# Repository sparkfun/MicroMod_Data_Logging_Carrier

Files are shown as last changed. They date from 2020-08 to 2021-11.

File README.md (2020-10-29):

SparkFun MicroMod Data Logging Carrier Board
========================================

SparkFun MicroMod Data Logging Carrier Board

[SparkFun MicroMod Data Logging Carrier Board (DEV-16829)](https://www.sparkfun.com/products/16829)

The SparkFun MicroMod Data Logging Carrier Board offers a highly customizable, low-power data logging platform using the MicroMod system allowing you to choose your own Processor Board to pair with the Carrier Board. The board features several connections for data collection including I<sup>2</sup>C, SPI and Serial UART.

Repository Contents
-------------------

* **/Examples** - Arduino example sketches
* **/Hardware** - Eagle design files (.brd, .sch)

Documentation
--------------
* **[Hookup Guide](https://learn.sparkfun.com/tutorials/micromod-data-logging-carrier-board-hookup-guide)** - Basic hookup guide for the SparkFun MicroMod Data Logging Carrier Board
* **[MicroMod Info Page](https://ww.sparkfun.com/micromod)** - MicroMod Information Page

Version History
---------------
* **[DEV-16829](https://www.sparkfun.com/products/16829)** - Initial release.

License Information
-------------------

This product is _**open source**_! 

Please review the LICENSE.md file for license information. 

If you have any questions or concerns on licensing, please contact technical support on our [SparkFun forums](https://forum.sparkfun.com/viewforum.php?f=152).

Distributed as-is; no warranty is given.

- Your friends at SparkFun.

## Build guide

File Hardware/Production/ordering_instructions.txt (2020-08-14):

panel size, 144x171mm
PCB thickness, 1.6mm
number of layers, 2
soldermask color, Red
silkscreen color, White
oz copper, 1oz
finish, HASL lead free
stencils, none
pcs per panel, 8
min trace width, 0.1778mm / 0.0070in
min drill size, 0.3048mm / 0.0120in

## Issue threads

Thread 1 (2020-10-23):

Hardware revision request: Voltage divider jumper pad

adamgarbo, 2020-10-23:
Hey folks,

If at some point there is a hardware revision of the MicroMod Data Logger Carrier Board, I would strongly suggest the addition of a jumper pad at the top of the 10kΩ/20kΩ voltage divider that would allow users to cut the voltage supply.

At present, this divider draws a constant 200 uA at 6V and there is no way to disable it, save for cutting the trace, or removing the SMD resistors with a hot air rework station.

Cheers,
Adam

nseidle, 2020-10-23:
A fine idea! Will do.

adamgarbo, 2020-10-28:
Hey @nseidle,

Just received a couple of shiny new Data Logger Carrier Boards today.

I haven't disabled the voltage divider yet, but am measuring a quiescent draw of **~700 uA** with a MicroMod Artemis Processor and 4.2 V lithium battery in deep sleep.

3V3 and VIN jumper pads cut, Qwiic and peripheral AP2112 regulators disabled, LEDs set OUTPUT/LOW and no microSD card is inserted. Assuming ~140 uA for the voltage divider, it appears **>500 uA** is being drawn elsewhere on the board.

Curious who the culprits are!

Cheers,
Adam

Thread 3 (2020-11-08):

Hardware revision request: Improved power efficiency

adamgarbo, 2020-11-08:
Hi there,

I've been super excited to get my hands on the MicroMod Data Logging Carrier Board (MMDLC). I've been putting it through its paces along with an Artemis Processor.

Unfortunately, the quiescent draw of the MMDLC is quite high, so my goal has been to track down the major current draw contributors in order to provide constructive feedback for the next hardware revision (which I realize may take some time). I believe with a few minor changes, the power efficiency of this carrier board could be really improved!

### Methods: Current Measurement
The first step was to characterize the current draw of the MMDLC under a number of different conditions (e.g. disabling LEDs, voltage divider, etc). My methods for measuring the current were as follows:

1. Charge RTC battery for >24 hours via USB-C/LiPo battery
2. Connect a 3.7 V lithium battery (4.2 V nominal), disconnect USB-C connection and allow LiPo charger circuit to settle
3. Place system in deep sleep using the Apollo3 Core RTC library example: `Example6 _LowPower_Alarm`  with added functionality to correctly power down I2C/SPI and G1/G2 pins
4. Disable the onboard voltage divider using a hot-air rework station to remove the top 20kΩ resistor
5. All current measurements were made across MEAS jumper with a Fluke 287 digital multimeter

### Results:

**Table 1.** Quiescent draw of MicroMod Data Logger Carrier Board & Artemis Processor using a 3.7 V (4.2 V) LiPo battery
3V3 LED | VIN LED | PWC | Qwiic | Voltage Divider | Quiescent Draw (mA)
:--: | :--: | :--: | :--: | :--: | :--:
TRUE | TRUE | FALSE | FALSE | TRUE | 2.570
FALSE | TRUE | FALSE | FALSE | TRUE | 0.930
FALSE | FALSE | FALSE | FALSE | TRUE | 0.475
FALSE | FALSE | FALSE | FALSE | FALSE | 0.290

### Discussion:

- Based on the results of Table 1, disabling both LEDs brings the quiescent draw to approximately 500 uA, which is a good start.
- The 20kΩ/10kΩ voltage divider was identified in issue #1 as drawing as much as 200 uA (constant) at 6 V. In this case, disabling the voltage divider by removing the top SMD resistor appeared to save 185 uA. A good savings, but not a modification the average user can will/can do.
- The lowest quiescent draw measured was approximately 290 uA. This is approximately 3-4x greater than the sleep current of other comparable data logging platforms, such as the Adafruit M0 Adalogger (~80 uA) or the SparkFun OpenLog Artemis (~80 uA).
- The question is, what are the sources of this 290 uA? Looking at the schematic and related datasheets, I was able to come up with the following values:

**Table 2.** Max quiescent draw of MMDLCB components
Component | Max Current Draw (uA)
:--: | :--:
AP7361C LDO Regulator | 80
PWC AP2112 LDO Regulator | 80
Qwiic AP2112 LDO Regulator | 80
MCP7381 LiPo Charger | 5?

Based on my experience, the AP2112 LDO regulators will draw around 60 uA. Adding this value for the PWC and Qwiic LDOs with the new AP7361C LDO and MCP7381 charger, I account for approximately 180 uA. This leaves another 100 uA being drawn from components I haven't yet been able to identify.

### Suggestions:
While I'm still trying to identify the other contributors to increased sleep current draw, my hope is to get the conversation started regarding potential modifications that could help to improve the overall power efficiency. A couple of suggestions include:

1. Add (back) P-channel MOSFETs to provide control over PWC/Qwiic regulators. Potential power savings: 160 uA.
    - I noticed in a previous version of the MMDLCB that there were MOSFETs present and in fact, the Hookup Guide still makes reference to them.
2. Voltage divider:
    - (Option 1) Add jumper pad to voltage divider to allow it to be disabled. Potential power savings: 200 uA.
    - (Option 2) Add MOSFET to voltage divider allowing it to be enabled/disabled using a GPIO pin. @PaulZC's Global Artemis Tracker does something similar with the very same voltage divider resistance values:

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

### Summary:
The MicroMod Data Logging Carrier Board has amazing potential and it'd be super if we could get this baby under 100 uA!

Cheers,
Adam

adamgarbo, 2020-11-18:
It just dawned on me that the two AP2112 LDO regulators would only draw a maximum of 1 uA when EN is pulled LOW, which means that there's no real need for P-MOSFETs to disable the power. :man_facepalming:

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

However, this has left me even more confused as to where all the quiescent draw is coming from. Perhaps I should be looking at the Artemis Processor? The investigation continues!

jurvanoerle, 2020-11-24:
Hi there Adam,
I have been trying to do the same power-measurements ( (MMDLC with an Artemis Processor), but I find much higher values.
With all leds disabled, and G0,G1 and G2 disabled (voltage divider in place) I find values >> 1 mA. (and fluctuating). Obviously, I'm doing something wrong.    I have 2 questions:
= could you show your arduino code so I can retry your measurements, and
= where can I find the resistor of the voltage divider I need to cut to reduce power

Regards, Jur

adamgarbo, 2020-11-24:
Hi @jurvanoerle,

Happy to share my code. It's essentially an adapted version of the Apollo3 Example6 _LowPower_Alarm. You can access it here:
https://github.com/adamgarbo/Cryologger_Iceberg_Tracking_Beacon/blob/release-candidate/Software/mmdlcb_artemis_low_power/mmdlcb_artemis_low_power.ino

Please keep in mind that the RTC battery backup onboard the MMDLC takes a *long* time to fully charge. I've found it takes more than 24 hours for the battery to completely charge and for the quiescent draw to achieve its lowest value. Your current draw will be much higher (and flucturate) while it is charging. Also note, as soon as you remove all power sources from the MMDLC, the battery appears to rapidly discharge itself and will require charging again.

I used a hot-air rework station to remove the top SMD resistor from the voltage divider (green arrow). If you prefer to cut the trace (**Warning: permanent change**), you can cut the small trace below the resistor marked by the yellow arrow.

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

Cheers,
Adam

adamgarbo, 2020-11-24:
Oh and before I forget, I believe I may have discovered the source of the high quiescent draw I observed. The CMOS op-amp on the Artemis Processor:

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

As best I can tell, this baby draws 31-50 uA per channel plus 45 uA quiescent draw to power itself. With four of the op-amp channels in use, this could explain the power draw measured with the MMDLCB and Artemis Processor. Hopefully, @nseidle can let us know if this is correct!

Cheers,
Adam

jurvanoerle, 2020-11-26:
Hi Adam,
I managed to brick my board removing the divider/resistor. A new board shows much better results.
The rtc battery discharges quickly indeed after removing all power: the processor and even I2C and leds are powered by the rtc battery, discharging in seconds. For a datalogger board you would expect that the rtc-battery only powers the rtc, lasting for month's: how can I prevent this discharge (cutting a trace somehwere?)
Regards, Jur

adamgarbo, 2020-11-26:
Hi Jur,

Sorry to hear about your board becoming bricked. I'm trying to think about how that could have happened! The voltage divider is in a pretty non-critical area. I've posted an image of the EAGLE board file with what should have been cut or removed in purple. I'm partial to removing the SMD resistor, as it can always be soldered back on.

Regarding the RTC battery backup discharging quickly, I think this will be something that also needs to be addressed in the next hardware revision. I get the sense that the MicroMod ecosystem is still in its infancy, and still has a lot of kinks to be worked out.

Cheers,
Adam

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

jurvanoerle, 2020-12-10:
Hi Adam,
I was succesfull in getting comparable results ( ~0,3 mA in deepsleep), which is perfect for my application, thanks.
BTW, I managed to brick my second carrier board also. On both boards, the serial port is not showing up anymore (not on a PC, nor on a Linux laptop). Is it possible to brick the fdti chip by software (eg by shutting down serial, or shutting down G0/G1/G2 in the arduino code; I have been experimenting a lot with these settings).
I have never experienced this with other arduino boards.
Regards, Jur

adamgarbo, 2021-01-05:
To provide a quick update, I measured the current draw of the MMDLCB with no processor board installed and powered by a 4.2V LiPo.

I made two measurements, as the AP2112 regulators are enabled by default, which required manually pulling their EN pins LOW.

3V3 LED | VIN LED | PWC | Qwiic | Voltage Divider | Quiescent Draw (uA)
-- | -- | -- | -- | -- | --
FALSE | FALSE | TRUE | TRUE | FALSE | 200
FALSE | FALSE | FALSE | FALSE | FALSE | 149

These current draws look to be accounted for by the AP7361C regulator (~80 uA) and the two 100 kΩ pull-up resistors on the AP2112 regulator EN pins (66 uA).

Doing the math, it looks like the Artemis Processor is consuming ~140 uA on its own.

While it'd be nice to see the AP2112s behind FETs, adding a jumper to the voltage divider is by far the easiest solution and would be ideal for all MicroMod carrier boards.

Closed 2021-01-05.

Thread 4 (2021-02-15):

Incorrect battery measurements

adamgarbo, 2021-02-15:
Hi folks,

I noticed that I was getting incorrect battery voltage measurements when powering the MMDLCB with a LiPo battery. After looking at the schematic, this seems to be due to the fact that VBAT has to pass through D3 before getting to the top of the voltage divider. With a multimeter, I measured a battery voltage of 4.2 V but only 4.1 V at the top of the voltage divider, meaning there's a voltage drop of ~0.1 V across D3.

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

This looks to apply to all MicroMod carrier boards with the onboard resistor divider. While it can be addressed using a correction factor in the code, it may be a good idea to add it to the list for the next hardware revision of the MMDLCB.

TL;DR: Feed onboard voltage divider with VBAT and not VIN

Cheers,
Adam

Closed 2024-11-13.

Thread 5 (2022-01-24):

no way to directly power with a 3.3V regulated input?

jerabaul29, 2022-01-24:
I looked at the schematics of this board; is it correct that there is no way to directly power the board with the 3.3V regulated output that typically comes out of a step up step down converter? If this is correct this is very sad, as this drastically limits the usability of the board :( .

Closed 2022-01-24.

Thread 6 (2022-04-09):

incorrect information about power control

paulvha, 2022-04-09:
Looking at the schematics, the hook-up guide, and the examples, the information about the power control is confusing/incorrect.

For both (G1 / Peripheral and G2 / QWIIC) the Enable pin on the LDO is pulled high with a resistor. Hence the power is ALWAYS ON !
_There is NO need for doing a power ON unless GPIO was pulled LOW in the sketch before!_ If people want to preserve power, they should power off the relevant LDO(s)

The hookup guide (https://learn.sparkfun.com/tutorials/micromod-data-logging-carrier-board-hookup-guide) states :

**Take note both Qwiic and 3V3 peripheral power are controlled with a P-Channel MOSFET so the logic is reversed (Power ON = LOW and Power OFF = HIGH).**

### This is 3 times incorrect :
1. There is NO MOSFET, but an LDO
2. Turning  POWER OFF = LOW  (NOT HIGH)
3. Turning POWER ON = HIGH ( which is already due to the pullup resistors.)

regards,
Paul

nseidle, 2022-04-12:
Thanks! Fixed.

Closed 2022-04-12.

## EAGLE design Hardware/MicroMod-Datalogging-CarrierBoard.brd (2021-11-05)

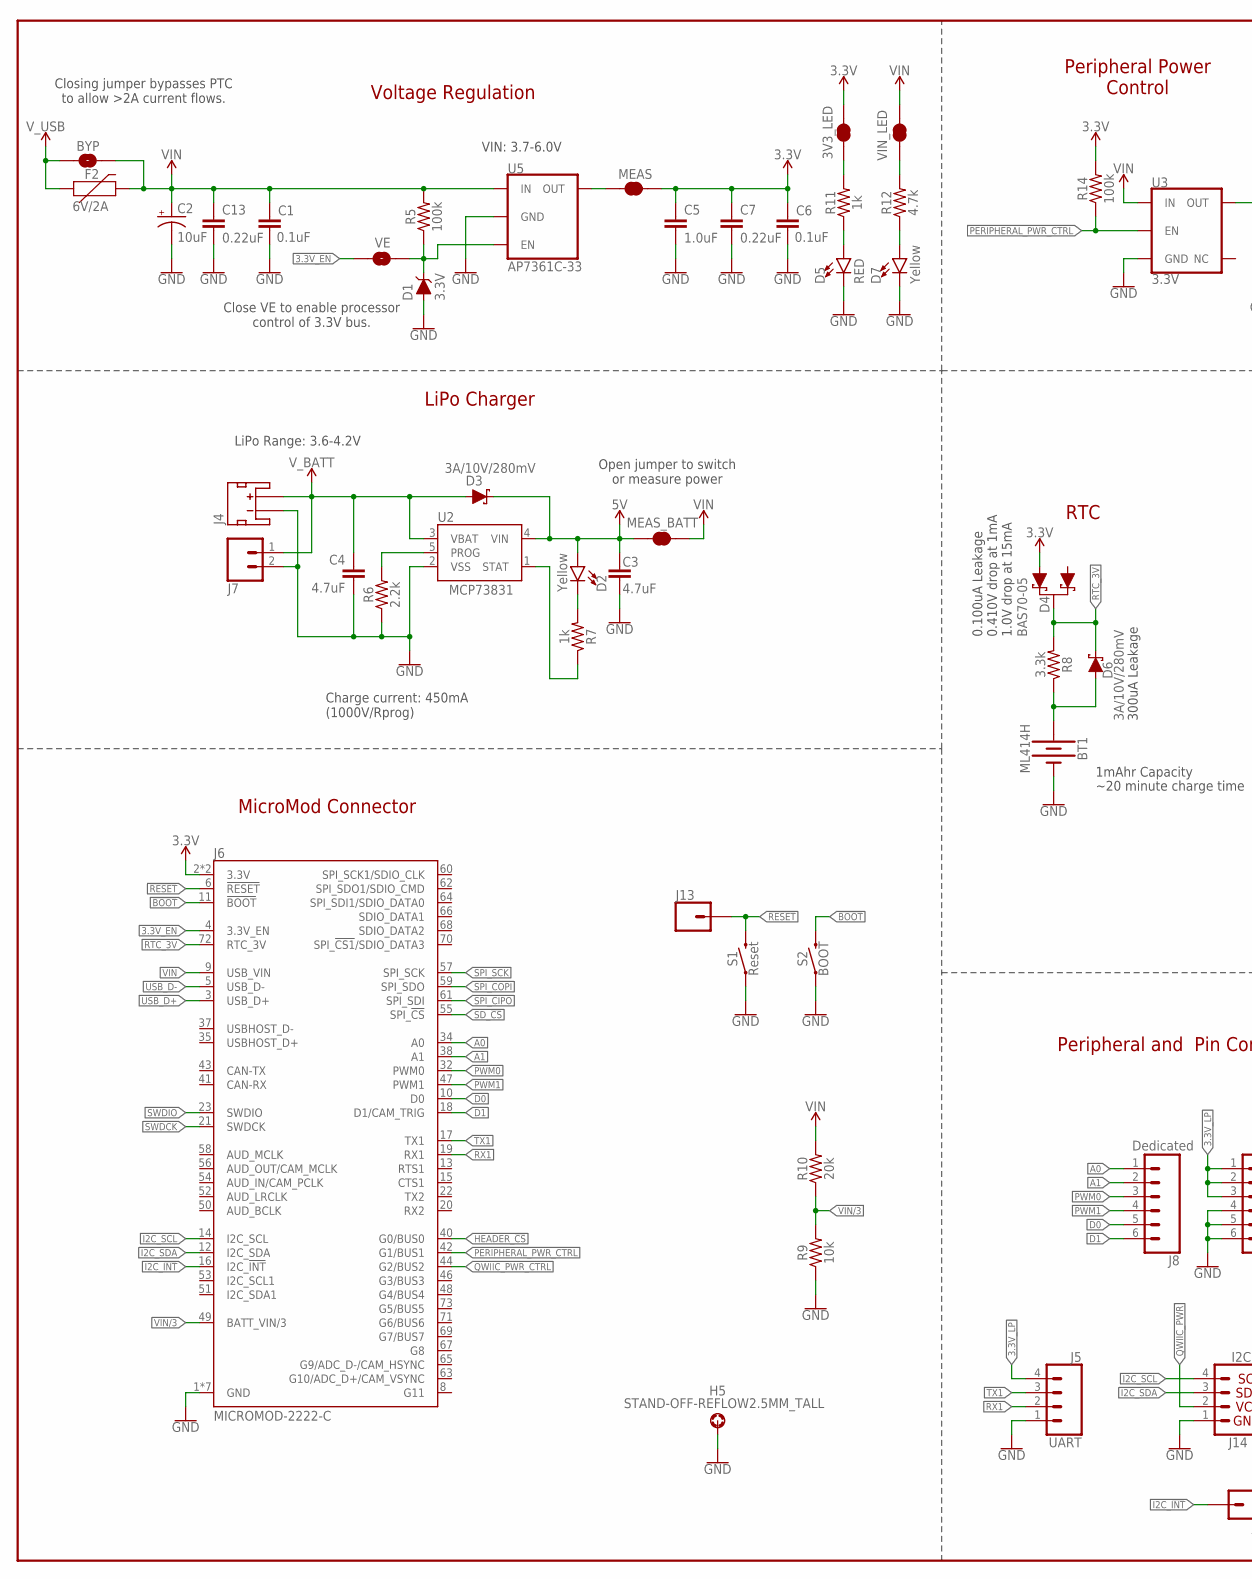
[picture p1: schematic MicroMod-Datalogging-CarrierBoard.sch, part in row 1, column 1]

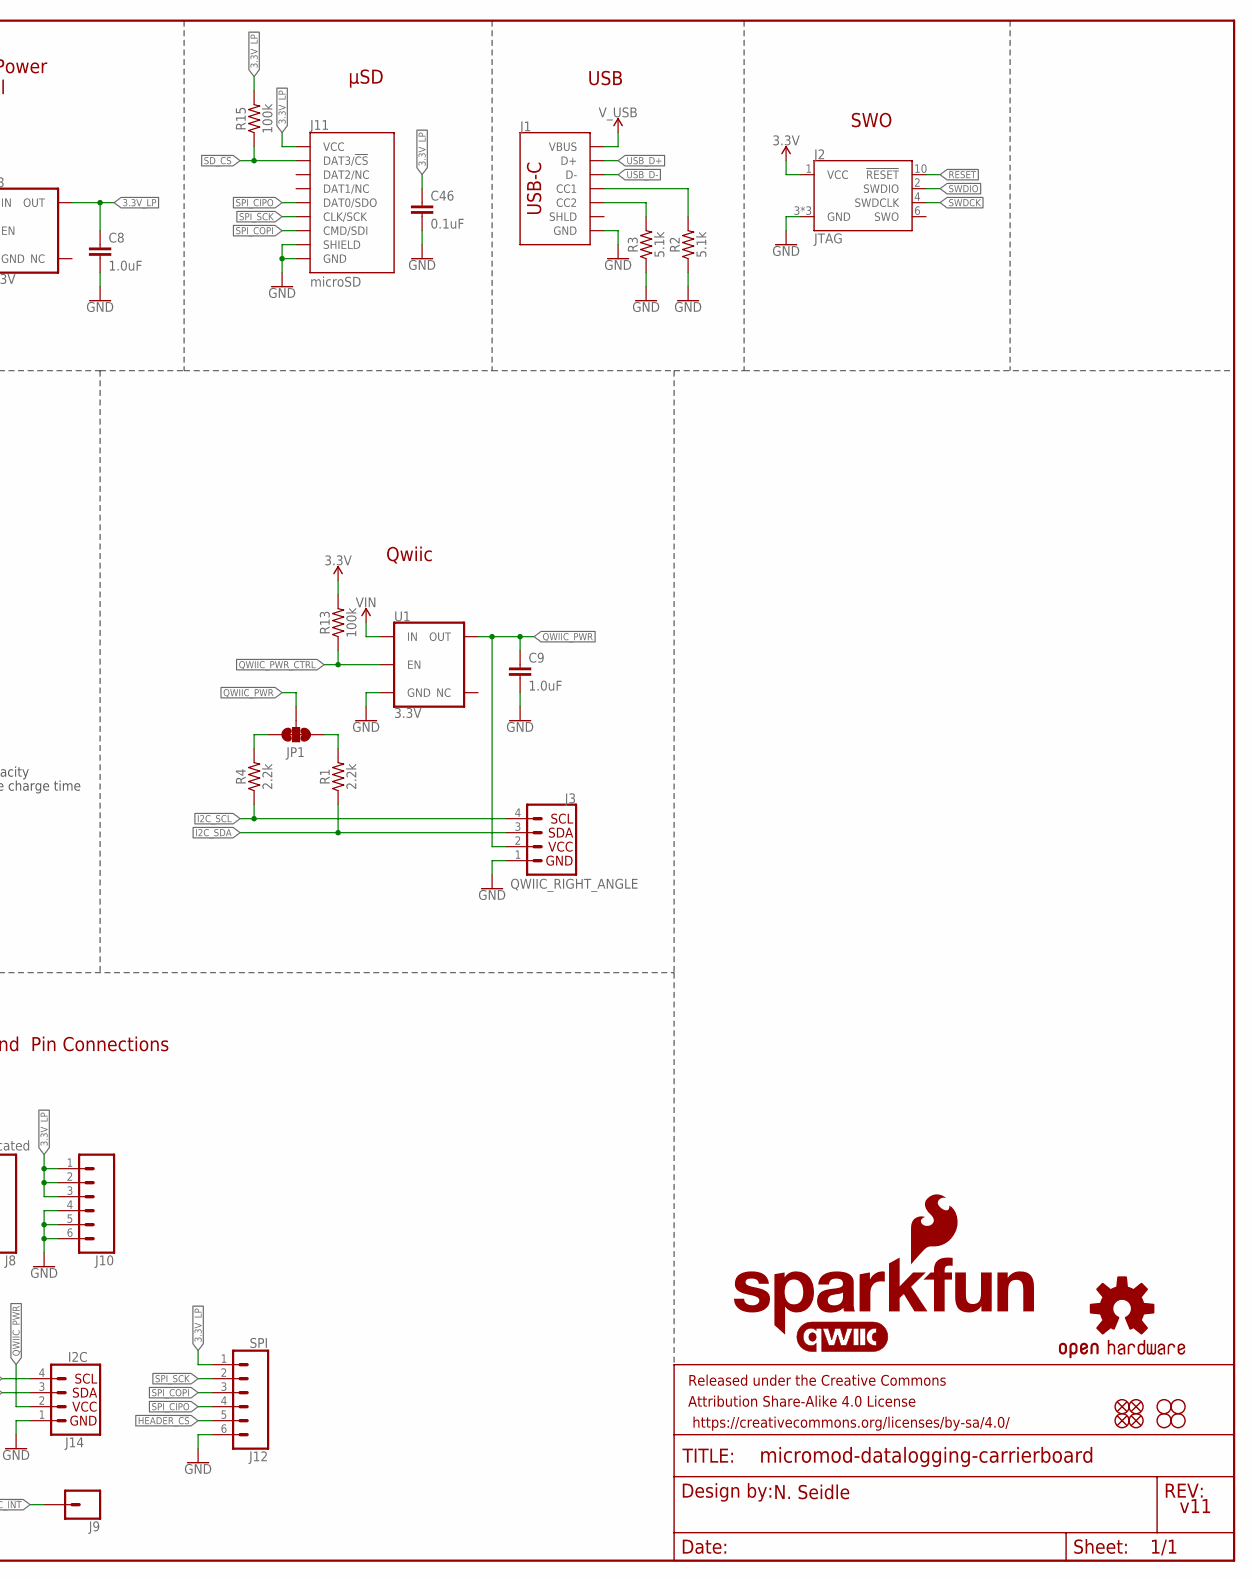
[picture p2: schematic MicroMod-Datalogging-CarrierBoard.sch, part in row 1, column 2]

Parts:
3V3_LED: JUMPER-SMT_2_NC_TRACE_SILK; SMT-JUMPER_2_NC_TRACE_SILK
BT1: ML414H; ML414H_IV01E
BYP: JUMPER-SMT_2_NO_SILK; SMT-JUMPER_2_NO_SILK
C1, C6, C46: 0.1uF; 0603
C2: 10uF; EIA3216
C3, C4: 4.7uF; 0603
C5, C8, C9: 1.0uF; 0603
C7, C13: 0.22uF; 0603
D1: 3.3V; SOD-323
D2, D7: Yellow; LED-0603
D3, D6: 3A/10V/280mV; SOD-323
D4: BAS70-05; SOT23-3
D5: RED; LED-0603
F2: 6V/2A; 1210
FD1, FD2, FD3, FD4: FIDUCIALUFIDUCIAL; FIDUCIAL-MICRO
FRAME1: FRAME-LEDGER; CREATIVE_COMMONS
H1, H2, H3, H4: STAND-OFF
H5: STAND-OFF-REFLOW2.5MM_TALL; STAND-OFF-REFLOW-M2.5
J1: USB_C_2-LAYER_PADS; USB-C-16P-2LAYER-PADS
J2: JTAG; 2X5-PTH-1.27MM
J3: QWIIC_RIGHT_ANGLE; JST04_1MM_RA
J4: JST_2MM_MALE; JST-2-SMD
J5: UART; 1X04_NO_SILK
J6: MICROMOD-2222-C; M.2-CONNECTOR-E
J7: CONN_021X02_NO_SILK; 1X02_NO_SILK
J8: Dedicated; 1X06_NO_SILK
J9, J13: CONN_01PTH_NO_SILK_YES_STOP; 1X01_NO_SILK
J10: CONN_06NO_SILK_NO_POP; 1X06_NO_SILK
J11: microSD; MICRO-SD-SOCKET
J12: SPI; 1X06_NO_SILK
J14: I2C; 1X04_NO_SILK
JP1: JUMPER-SMT_3_2-NC_TRACE_SILK; SMT-JUMPER_3_2-NC_TRACE_SILK
LOGO1: SFE_LOGO_NAME_FLAME.1_INCH; SFE_LOGO_NAME_FLAME_.1
LOGO2: QWIIC_LOGO_CONNECTOR; QWIIC_5.5MM
LOGO3: OSHW-LOGOMINI; OSHW-LOGO-MINI
MEAS: JUMPER-COMBO_2_NC_TRACE; COMBO-JUMPER_2_NC_TRACE
MEAS_BATT: JUMPER-COMBO_2_NC_TRACE; COMBO-JUMPER_2_NC_TRACE
R1, R4, R6: 2.2k; 0603
R2, R3: 5.1k; 0603
R5, R13, R14, R15: 100k; 0603
R7, R11: 1k; 0603
R8: 3.3k; 0603
R9: 10k; 0603
R10: 20k; 0603
R12: 4.7k; 0603
S1: Reset; TACTILE_SWITCH_SMD_5.2MM
S2: BOOT; TACTILE_SWITCH_SMD_5.2MM
U1, U3: 3.3V; SOT23-5
U2: MCP73831; SOT23-5
U5: AP7361C-33; UDFN-8
VE: JUMPER-SMT_2_NO_SILK; SMT-JUMPER_2_NO_SILK
VIN_LED: JUMPER-SMT_2_NC_TRACE_SILK; SMT-JUMPER_2_NC_TRACE_SILK

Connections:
3.3V: 3V3_LED.2, C5.1, C6.1, C7.1, D4.2 (A1), J2.1 (VCC), J6.2 (3.3V), J6.74 (3.3V), MEAS.2, MEAS.4 (2), R13.2, R14.2
3.3V_EN: J6.4 (3.3V_EN), VE.1
3.3V_EN_VE: D1.C, R5.1, U5.5 (EN), VE.2
3.3V_LP: C8.1, C46.1, J5.4, J10.1, J10.2, J10.3, J11.VCC, J12.1, R15.2, U3.5 (OUT)
5V: C3.1, D2.A, D3.C, MEAS_BATT.1, MEAS_BATT.3 (1), U2.4 (VIN)
!BOOT!: J6.11 (!BOOT!), S2.3 (2), S2.4 (2)
!RESET!: J2.10 (!RESET), J6.6 (!RESET!), J13.1, S1.3 (2), S1.4 (2)
A0: J6.34 (A0), J8.1
A1: J6.38 (A1), J8.2
CHG_LED: R7.1, U2.1 (STAT)
D0: J6.10 (D0), J8.5
D1: J6.18 (D1/CAM_TRIG), J8.6
GND: BT1.-, C1.2, C2.-, C3.2, C4.2, C5.2, C6.2, C7.2, C8.2, C9.2, C13.2, C46.2, D1.A, D5.C, D7.C, H5.1, J1.GND, J1.GND2 (GND), J2.3 (GND), J2.5 (GND), J2.9 (GND), J3.1, J4.1 (-), J5.1, J6.1 (GND), J6.7 (GND), J6.33 (GND), J6.36 (GND), J6.39 (GND), J6.45 (GND), J6.75 (GND), J7.2, J10.4, J10.5, J10.6, J11.CD1 (SHIELD), J11.GND, J11.GND1 (GND), J11.GND3 (GND), J12.6, J14.1, R2.1, R3.1, R6.1, R9.1, S1.1, S1.2 (1), S2.1, S2.2 (1), U1.2 (GND), U2.2 (VSS), U3.2 (GND), U5.4 (GND), U5.EP (GND)
HEADER_!CS!: J6.40 (G0/BUS0), J12.5
I2C_!INT!: J6.16 (I2C_!INT!), J9.1
I2C_SCL: J3.4, J6.14 (I2C_SCL), J14.4, R4.1
I2C_SDA: J3.3, J6.12 (I2C_SDA), J14.3, R1.1
unnamed: MEAS.1, MEAS.3 (1), U5.1 (OUT)
unnamed: JP1.3, R4.2
unnamed: JP1.1, R1.2
unnamed: D2.C, R7.2
unnamed: D5.A, R11.1
unnamed: 3V3_LED.1, R11.2
unnamed: R6.2, U2.5 (PROG)
unnamed: R12.2, VIN_LED.1
unnamed: D7.A, R12.1
unnamed: J1.A5 (CC1), R2.2
unnamed: J1.B5 (CC2), R3.2
unnamed: BT1.+, D6.A, R8.1
PERIPHERAL_PWR_CTRL: J6.42 (G1/BUS1), R14.1, U3.3 (EN)
PWM0: J6.32 (PWM0), J8.3
PWM1: J6.47 (PWM1), J8.4
QWIIC_PWR: C9.1, J3.2, J14.2, JP1.2, U1.5 (OUT)
QWIIC_PWR_CTRL: J6.44 (G2/BUS2), R13.1, U1.3 (EN)
RTC_3V: D4.3 (C), D6.C, J6.72 (RTC_3V), R8.2
RX1: J5.2, J6.19 (RX1)
SD_!CS!: J6.55 (SPI_!CS!), J11.CS/DAT3 (DAT3/!CS!), R15.1
SPI_CIPO: J6.61 (SPI_SDI), J11.DO/DAT0 (DAT0/SDO), J12.4
SPI_COPI: J6.59 (SPI_SDO), J11.DI/CMD (CMD/SDI), J12.3
SPI_SCK: J6.57 (SPI_SCK), J11.SCLK (CLK/SCK), J12.2
SWDCK: J2.4 (SWDCLK), J6.21 (SWDCK)
SWDIO: J2.2 (SWDIO), J6.23 (SWDIO)
TX1: J5.3, J6.17 (TX1)
USB_D+: J1.A6 (D+), J1.B6 (D+), J6.3 (USB_D+)
USB_D-: J1.A7 (D-), J1.B7 (D-), J6.5 (USB_D-)
VIN: BYP.2, C1.1, C2.+, C13.1, F2.2, J6.9 (USB_VIN), MEAS_BATT.2, MEAS_BATT.4 (2), R5.2, R10.2, U1.1 (IN), U3.1 (IN), U5.8 (IN), VIN_LED.2
VIN/3: J6.49 (BATT_VIN/3), R9.2, R10.1
V_BATT: C4.1, D3.A, J4.2 (+), J7.1, U2.3 (VBAT)
V_USB: BYP.1, F2.1, J1.VBUS1 (VBUS), J1.VBUS2 (VBUS)

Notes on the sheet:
μSD
300uA Leakage
~20 minute charge time
1mAhr Capacity
SWO
USB
Peripheral and Pin Connections
Qwiic
RTC
Voltage Regulation
MicroMod Connector
LiPo Charger
LiPo Range: 3.6-4.2V
Charge current: 450mA (1000V/Rprog)
Open jumper to switch or measure power
Peripheral Power Control
0.100uA Leakage 0.410V drop at 1mA 1.0V drop at 15mA
Closing jumper bypasses PTC to allow >2A current flows.
VIN: 3.7-6.0V
N. Seidle
v11
Close VE to enable processor control of 3.3V bus.

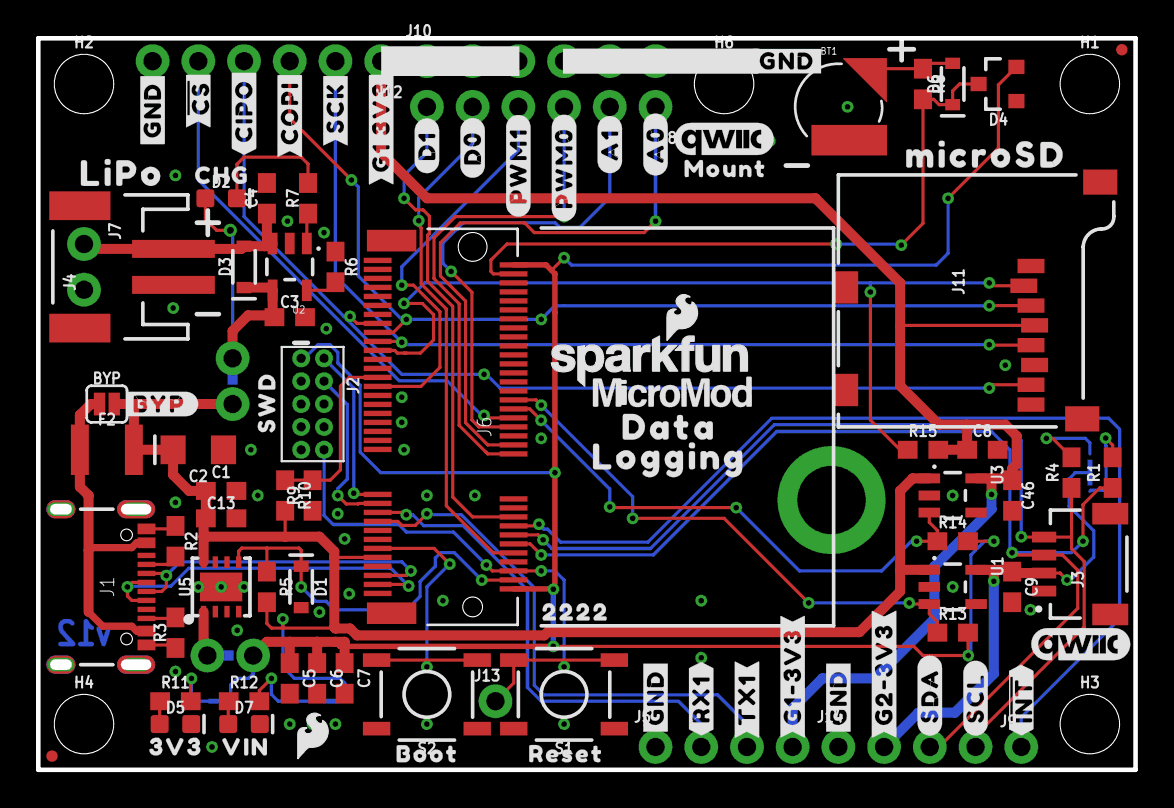
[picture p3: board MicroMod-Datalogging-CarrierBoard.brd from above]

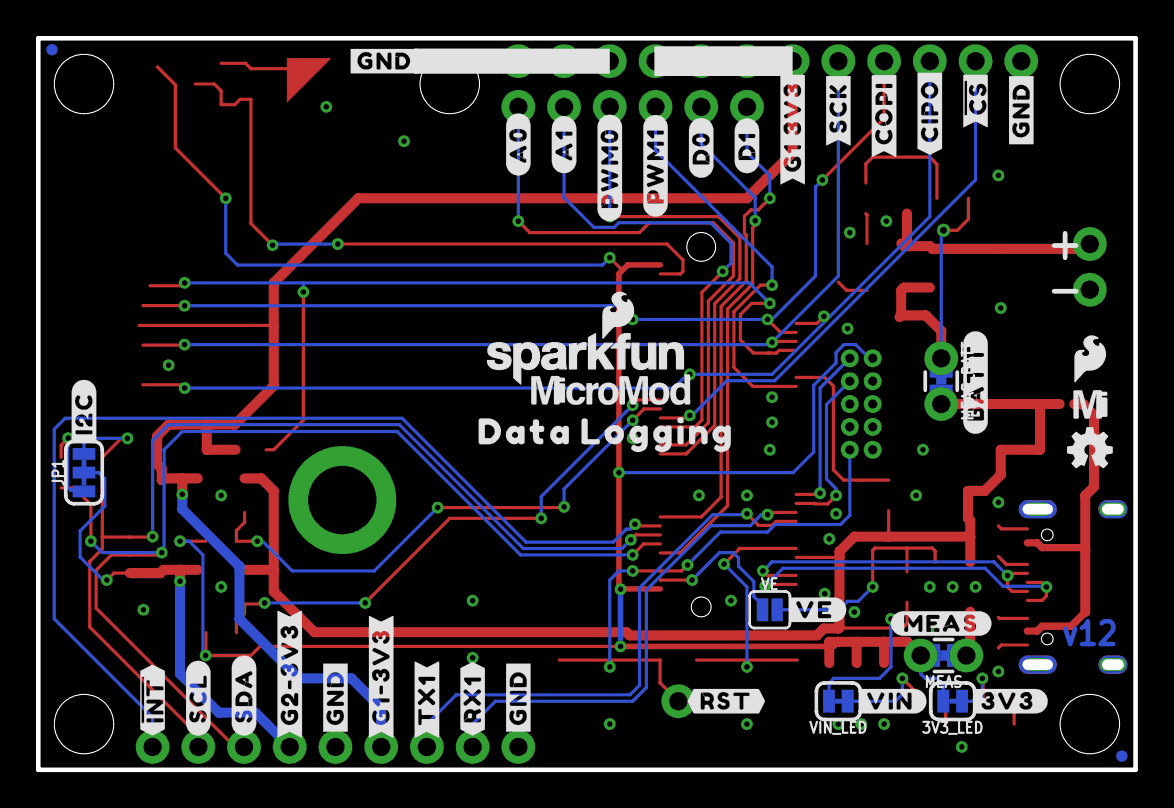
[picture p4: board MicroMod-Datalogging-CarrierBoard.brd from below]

Board: 2 copper layers, 61.0 x 40.6 mm, 149 parts (44 on the bottom side), 49 nets.

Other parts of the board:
H6: STAND-OFF
LOGO4: SFE_LOGO_NAME_FLAME.1_INCH; SFE_LOGO_NAME_FLAME_.1
LOGO5: QWIIC_LOGO_CONNECTOR; QWIIC_5.5MM
U$1, U$66: SFE_LOGO_FLAME_.1
U$2, U$76: #D1#0
U$3, U$77: #D0#0
U$4: #3V3#2
U$5: #BATT#0
U$6, U$18, U$24, U$27, U$32, U$34, U$36, U$42: #GND#0
U$7, U$8: #SCK#0
U$9, U$81: #PWM1#1
U$10, U$80: #PWM0#0
U$11: MICROSD0
U$12, U$79: #A1#2
U$13, U$78: #A0#3
U$14: MOUNT0
U$15: LIPO0
U$16, U$23: DATA0
U$17, U$86: #RX1#1
U$19, U$26: LOGGING1
U$20: 22220
U$21, U$89: #TX1#2
U$22: #I2C#0
U$25, U$90: #G1#3V3#0
U$28: #MEAS#3
U$29, U$83: #G2#3V3#3
U$30: #RST#0
U$31, U$88: #SDA#4
U$33: #VIN#1
U$35, U$87: #SCL#5
U$37, U$63: MICROMOD_LOGO_.35
U$38, U$82: ##INT##6
U$39, U$40: #CIPO#0
U$41: #VE#0
U$50, U$51: ##CS##0
U$62: MICROMOD_MI_LOGO_.35
U$64, U$65: #G1_3V3#0
U$72, U$73: #COPI#0
U$91: BOOT0
U$92: RESET1
U$93: 3V30
U$94: VIN1
U$95: #BYP#3
U$96: CHG1
U$97: SWD0

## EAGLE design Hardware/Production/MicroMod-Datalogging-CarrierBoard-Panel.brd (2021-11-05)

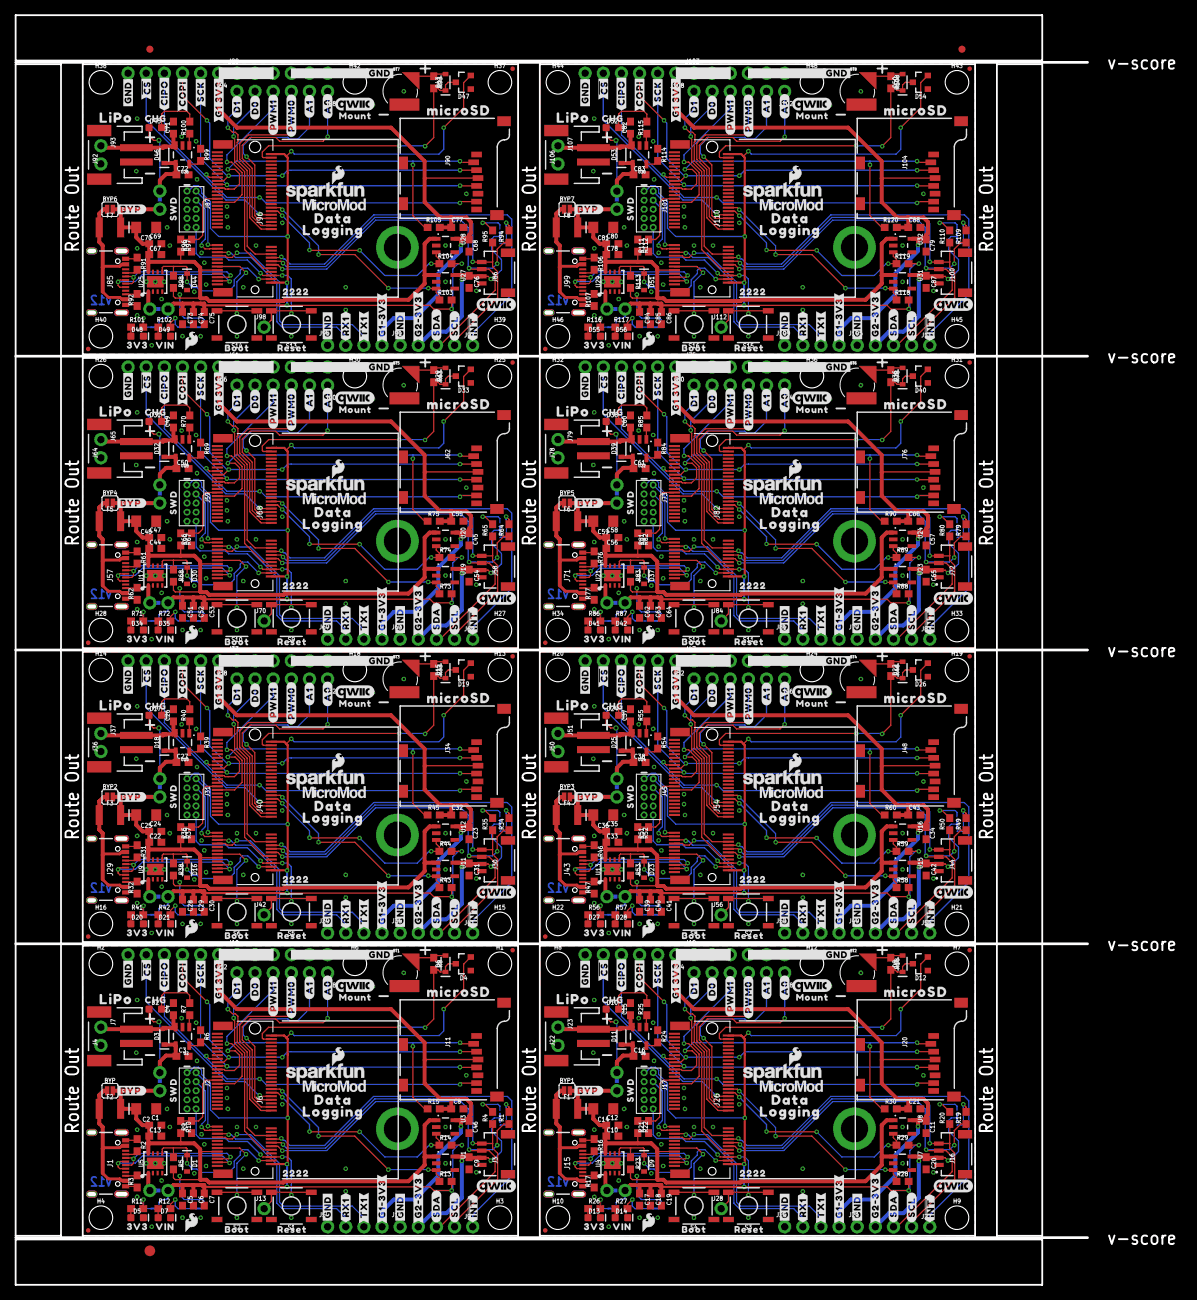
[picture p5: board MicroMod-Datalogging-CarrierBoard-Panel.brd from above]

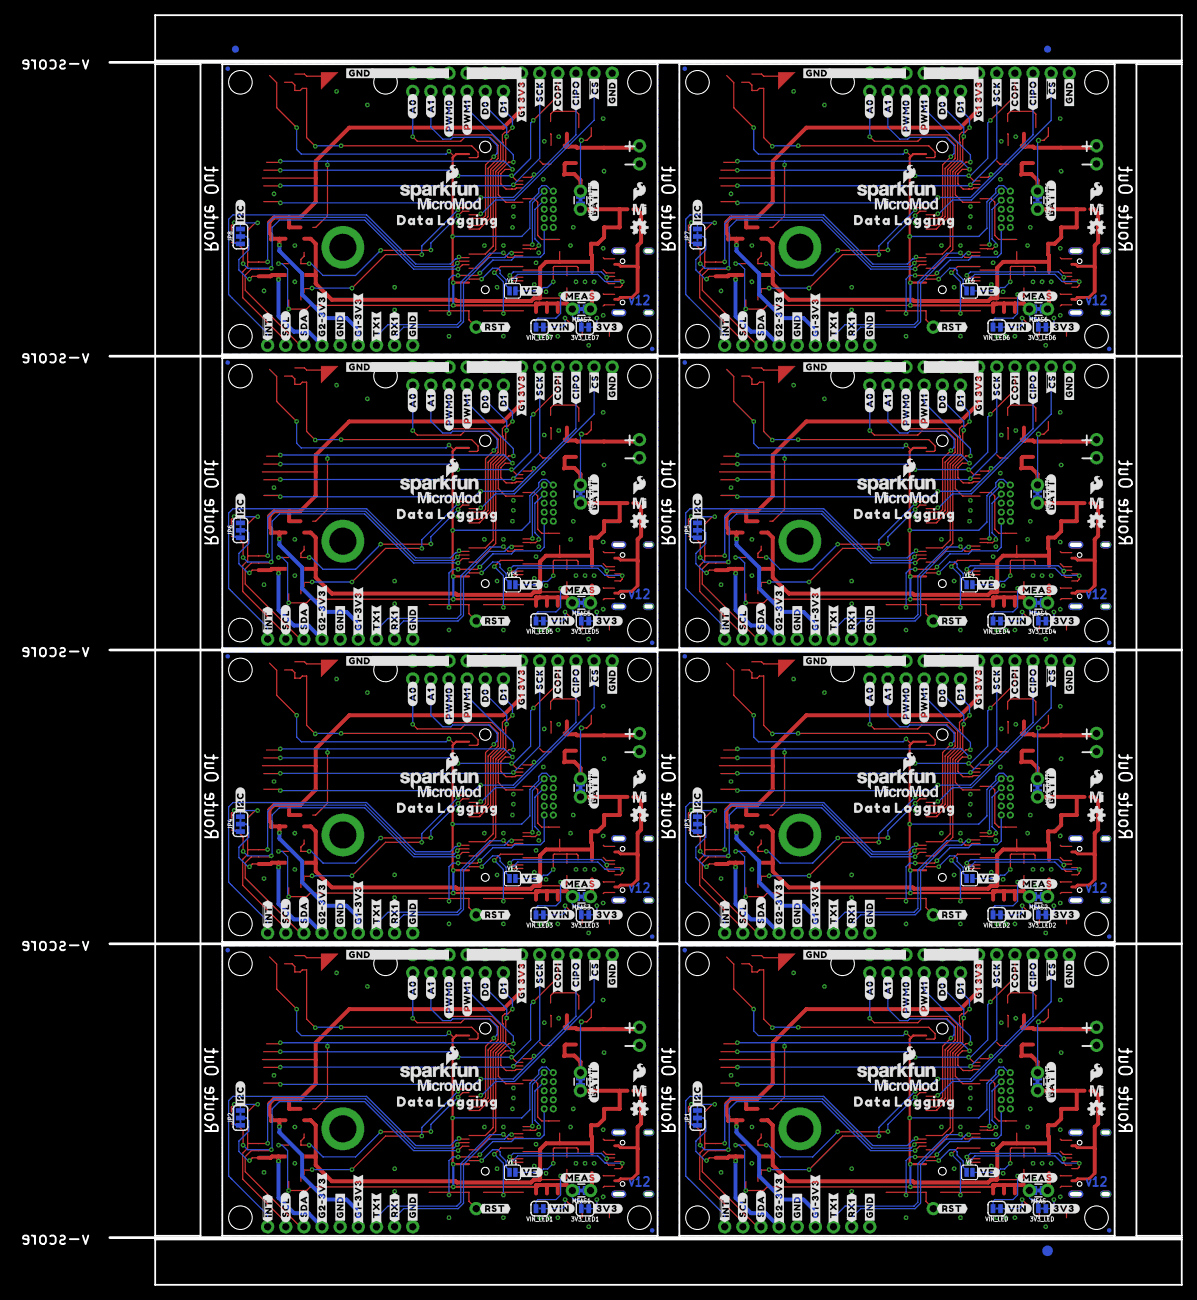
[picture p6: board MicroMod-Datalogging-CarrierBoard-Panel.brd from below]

Board: 2 copper layers, 150.1 x 177.8 mm, 1190 parts (355 on the bottom side), 392 nets.

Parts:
3V3_LED, 3V3_LED1, 3V3_LED2, 3V3_LED3, 3V3_LED4, 3V3_LED5, 3V3_LED6, 3V3_LED7: SMT-JUMPER_2_NC_TRACE_SILK
BT1, BT2, BT3, BT4, BT5, BT6, BT7, BT8: ML414H; ML414H_IV01E
BYP, BYP1, BYP2, BYP3, BYP4, BYP5, BYP6, BYP7: JUMPER-SMT_2_NO_SILK; SMT-JUMPER_2_NO_SILK
C1, C6, C11, C12, C18, C23, C24, C29, C34, C35, C40, C45, C46, C47, C52, C57, C58, C63, C68, C69, C74, C79, C80, C85: 0.1uF; 0603
C2, C14, C25, C36, C48, C59, C70, C81: 10uF; EIA3216
C3, C4, C15, C16, C26, C27, C37, C38, C49, C50, C60, C61, C71, C72, C82, C83: 4.7uF; 0603
C5, C8, C9, C17, C20, C21, C28, C31, C32, C39, C42, C43, C51, C54, C55, C62, C65, C66, C73, C76, C77, C84, C87, C88: 1.0uF; 0603
C7, C10, C13, C19, C22, C30, C33, C41, C44, C53, C56, C64, C67, C75, C78, C86: 0.22uF; 0603
D1, D9, D16, D23, D30, D37, D44, D51: 3.3V; SOD-323
D2, D7, D10, D14, D17, D21, D24, D28, D31, D35, D38, D42, D45, D49, D52, D56: Yellow; LED-0603
D3, D6, D8, D11, D15, D18, D22, D25, D29, D32, D36, D39, D43, D46, D50, D53: 3A/10V/280mV; SOD-323
D4, D12, D19, D26, D33, D40, D47, D54: BAS70-05; SOT23-3
D5, D13, D20, D27, D34, D41, D48, D55: RED; LED-0603
E$1, E$2, E$3, E$4: FIDUCIAL-1X2
E$5, E$6: FIDUCIAL-1.5X3
F1, F2, F3, F4, F5, F6, F7, F8: 6V/2A; 1210
FD1, FD2, FD3, FD4, FD5, FD6, FD7, FD8, FD9, FD10, FD11, FD12, FD13, FD14, FD15, FD16, FD17, FD18, FD19, FD20, FD21, FD22, FD23, FD24, FD25, FD26, FD27, FD28, FD29, FD30, FD31, FD32: FIDUCIALUFIDUCIAL; FIDUCIAL-MICRO
H1, H2, H3, H4, H6, H7, H8, H9, H10, H12, H13, H14, H15, H16, H18, H19, H20, H21, H22, H24, H25, H26, H27, H28, H30, H31, H32, H33, H34, H36, H37, H38, H39, H40, H42, H43, H44, H45, H46, H48: STAND-OFF
H5, H11, H17, H23, H29, H35, H41, H47: STAND-OFF-REFLOW2.5MM_TALL; STAND-OFF-REFLOW-M2.5
J1, J15, J29, J43, J57, J71, J85, J99: USB-C-16P-2LAYER-PADS
J2, J17, J31, J45, J59, J73, J87, J101: JTAG; 2X5-PTH-1.27MM
J3, J16, J30, J44, J58, J72, J86, J100: QWIIC_RIGHT_ANGLE; JST04_1MM_RA
J4, J22, J36, J50, J64, J78, J92, J106: JST-2-SMD
J5, J25, J39, J53, J67, J81, J95, J109: UART; 1X04_NO_SILK
J6, J26, J40, J54, J68, J82, J96, J110: MICROMOD-2222-C; M.2-CONNECTOR-E
J7, J23, J37, J51, J65, J79, J93, J107: 1X02_NO_SILK
J8, J18, J32, J46, J60, J74, J88, J102: Dedicated; 1X06_NO_SILK
J9, J13, J27, J28, J41, J42, J55, J56, J69, J70, J83, J84, J97, J98, J111, J112: 1X01_NO_SILK
J10, J19, J33, J47, J61, J75, J89, J103: 1X06_NO_SILK
J11, J20, J34, J48, J62, J76, J90, J104: microSD; MICRO-SD-SOCKET
J12, J24, J38, J52, J66, J80, J94, J108: SPI; 1X06_NO_SILK
J14, J21, J35, J49, J63, J77, J91, J105: I2C; 1X04_NO_SILK
JP1, JP2, JP3, JP4, JP5, JP6, JP7, JP8: SMT-JUMPER_3_2-NC_TRACE_SILK
LOGO1, LOGO4, LOGO6, LOGO9, LOGO11, LOGO14, LOGO16, LOGO19, LOGO21, LOGO24, LOGO26, LOGO29, LOGO31, LOGO34, LOGO36, LOGO39: SFE_LOGO_NAME_FLAME.1_INCH; SFE_LOGO_NAME_FLAME_.1
LOGO2, LOGO5, LOGO7, LOGO10, LOGO12, LOGO15, LOGO17, LOGO20, LOGO22, LOGO25, LOGO27, LOGO30, LOGO32, LOGO35, LOGO37, LOGO40: QWIIC_LOGO_CONNECTOR; QWIIC_5.5MM
LOGO3, LOGO8, LOGO13, LOGO18, LOGO23, LOGO28, LOGO33, LOGO38: OSHW-LOGOMINI; OSHW-LOGO-MINI
MEAS, MEAS1, MEAS2, MEAS3, MEAS4, MEAS5, MEAS6, MEAS7: COMBO-JUMPER_2_NC_TRACE
MEAS_BATT, MEAS_BATT1, MEAS_BATT2, MEAS_BATT3, MEAS_BATT4, MEAS_BATT5, MEAS_BATT6, MEAS_BATT7: COMBO-JUMPER_2_NC_TRACE
R1, R4, R6, R19, R20, R24, R34, R35, R39, R49, R50, R54, R64, R65, R69, R79, R80, R84, R94, R95, R99, R109, R110, R114: 2.2k; 0603
R2, R3, R16, R17, R31, R32, R46, R47, R61, R62, R76, R77, R91, R92, R106, R107: 5.1k; 0603
R5, R13, R14, R15, R23, R28, R29, R30, R38, R43, R44, R45, R53, R58, R59, R60, R68, R73, R74, R75, R83, R88, R89, R90, R98, R103, R104, R105, R113, R118, R119, R120: 100k; 0603
R7, R11, R25, R26, R40, R41, R55, R56, R70, R71, R85, R86, R100, R101, R115, R116: 1k; 0603
R8, R18, R33, R48, R63, R78, R93, R108: 3.3k; 0603
R9, R21, R36, R51, R66, R81, R96, R111: 10k; 0603
R10, R22, R37, R52, R67, R82, R97, R112: 20k; 0603
R12, R27, R42, R57, R72, R87, R102, R117: 4.7k; 0603
S1, S3, S5, S7, S9, S11, S13, S15: Reset; TACTILE_SWITCH_SMD_5.2MM
S2, S4, S6, S8, S10, S12, S14, S16: BOOT; TACTILE_SWITCH_SMD_5.2MM
U1, U3, U7, U8, U11, U12, U15, U16, U19, U20, U23, U24, U27, U28, U31, U32: 3.3V; SOT23-5
U2, U6, U10, U14, U18, U22, U26, U30: MCP73831; SOT23-5
U4, U5, U9, U13, U17, U21, U25, U29: AP7361C-33; UDFN-8
U$1, U$45, U$47, U$66, U$145, U$147, U$216, U$218, U$287, U$289, U$358, U$360, U$429, U$431, U$500, U$502: SFE_LOGO_FLAME_.1
U$2, U$58, U$76, U$118, U$156, U$189, U$227, U$260, U$298, U$331, U$369, U$402, U$440, U$473, U$511, U$544: #D1#0
U$3, U$59, U$77, U$119, U$157, U$190, U$228, U$261, U$299, U$332, U$370, U$403, U$441, U$474, U$512, U$545: #D0#0
U$4, U$133, U$204, U$275, U$346, U$417, U$488, U$559: #3V3#2
U$5, U$137, U$208, U$279, U$350, U$421, U$492, U$563: #BATT#0
U$6, U$18, U$24, U$27, U$32, U$34, U$36, U$42, U$105, U$106, U$107, U$108, U$109, U$110, U$138, U$142, U$176, U$177, U$178, U$179, U$180, U$181, U$209, U$213, U$247, U$248, U$249, U$250, U$251, U$252, U$280, U$284, U$318, U$319, U$320, U$321, U$322, U$323, U$351, U$355, U$389, U$390, U$391, U$392, U$393, U$394, U$422, U$426, U$460, U$461, U$462, U$463, U$464, U$465, U$493, U$497, U$531, U$532, U$533, U$534, U$535, U$536, U$564, U$568: #GND#0
U$7, U$8, U$52, U$53, U$150, U$151, U$221, U$222, U$292, U$293, U$363, U$364, U$434, U$435, U$505, U$506: #SCK#0
U$9, U$68, U$81, U$120, U$161, U$191, U$232, U$262, U$303, U$333, U$374, U$404, U$445, U$475, U$516, U$546: #PWM1#1
U$10, U$67, U$80, U$121, U$160, U$192, U$231, U$263, U$302, U$334, U$373, U$405, U$444, U$476, U$515, U$547: #PWM0#0
U$11, U$125, U$196, U$267, U$338, U$409, U$480, U$551: MICROSD0
U$12, U$61, U$79, U$122, U$159, U$193, U$230, U$264, U$301, U$335, U$372, U$406, U$443, U$477, U$514, U$548: #A1#2
U$13, U$60, U$78, U$123, U$158, U$194, U$229, U$265, U$300, U$336, U$371, U$407, U$442, U$478, U$513, U$549: #A0#3
U$14, U$124, U$195, U$266, U$337, U$408, U$479, U$550: MOUNT0
U$15, U$126, U$197, U$268, U$339, U$410, U$481, U$552: LIPO0
U$16, U$23, U$127, U$130, U$198, U$201, U$269, U$272, U$340, U$343, U$411, U$414, U$482, U$485, U$553, U$556: DATA0
U$17, U$71, U$86, U$111, U$164, U$182, U$235, U$253, U$306, U$324, U$377, U$395, U$448, U$466, U$519, U$537: #RX1#1
U$19, U$26, U$128, U$131, U$199, U$202, U$270, U$273, U$341, U$344, U$412, U$415, U$483, U$486, U$554, U$557: LOGGING1
U$20, U$129, U$200, U$271, U$342, U$413, U$484, U$555: 22220
U$21, U$84, U$89, U$112, U$167, U$183, U$238, U$254, U$309, U$325, U$380, U$396, U$451, U$467, U$522, U$538: #TX1#2
U$22, U$132, U$203, U$274, U$345, U$416, U$487, U$558: #I2C#0
U$25, U$85, U$90, U$113, U$168, U$184, U$239, U$255, U$310, U$326, U$381, U$397, U$452, U$468, U$523, U$539: #G1#3V3#0
U$28, U$134, U$205, U$276, U$347, U$418, U$489, U$560: #MEAS#3
U$29, U$70, U$83, U$114, U$163, U$185, U$234, U$256, U$305, U$327, U$376, U$398, U$447, U$469, U$518, U$540: #G2#3V3#3
U$30, U$135, U$206, U$277, U$348, U$419, U$490, U$561: #RST#0
U$31, U$75, U$88, U$115, U$166, U$186, U$237, U$257, U$308, U$328, U$379, U$399, U$450, U$470, U$521, U$541: #SDA#4
U$33, U$136, U$207, U$278, U$349, U$420, U$491, U$562: #VIN#1
U$35, U$74, U$87, U$116, U$165, U$187, U$236, U$258, U$307, U$329, U$378, U$400, U$449, U$471, U$520, U$542: #SCL#5
U$37, U$44, U$46, U$63, U$144, U$146, U$215, U$217, U$286, U$288, U$357, U$359, U$428, U$430, U$499, U$501: MICROMOD_LOGO_.35
U$38, U$69, U$82, U$117, U$162, U$188, U$233, U$259, U$304, U$330, U$375, U$401, U$446, U$472, U$517, U$543: ##INT##6
U$39, U$40, U$139, U$140, U$210, U$211, U$281, U$282, U$352, U$353, U$423, U$424, U$494, U$495, U$565, U$566: #CIPO#0
U$41, U$141, U$212, U$283, U$354, U$425, U$496, U$567: #VE#0
U$43, U$62, U$143, U$214, U$285, U$356, U$427, U$498: MICROMOD_MI_LOGO_.35
U$48, U$49, U$72, U$73, U$148, U$149, U$219, U$220, U$290, U$291, U$361, U$362, U$432, U$433, U$503, U$504: #COPI#0
U$50, U$51, U$54, U$55, U$152, U$153, U$223, U$224, U$294, U$295, U$365, U$366, U$436, U$437, U$507, U$508: ##CS##0
U$56, U$57, U$64, U$65, U$154, U$155, U$225, U$226, U$296, U$297, U$367, U$368, U$438, U$439, U$509, U$510: #G1_3V3#0
U$91, U$98, U$169, U$240, U$311, U$382, U$453, U$524: BOOT0
U$92, U$99, U$170, U$241, U$312, U$383, U$454, U$525: RESET1
U$93, U$100, U$171, U$242, U$313, U$384, U$455, U$526: 3V30
U$94, U$101, U$172, U$243, U$314, U$385, U$456, U$527: VIN1
U$95, U$102, U$173, U$244, U$315, U$386, U$457, U$528: #BYP#3
U$96, U$103, U$174, U$245, U$316, U$387, U$458, U$529: CHG1
U$97, U$104, U$175, U$246, U$317, U$388, U$459, U$530: SWD0
VE, VE1, VE2, VE3, VE4, VE5, VE6, VE7: SMT-JUMPER_2_NO_SILK
VIN_LED, VIN_LED1, VIN_LED2, VIN_LED3, VIN_LED4, VIN_LED5, VIN_LED6, VIN_LED7: SMT-JUMPER_2_NC_TRACE_SILK

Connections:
3.3V: 3V3_LED.2, C5.1, C6.1, C7.1, D4.2, J2.1, J6.2, J6.74, MEAS.2, MEAS.4, R13.2, R14.2
3.3V1: 3V3_LED1.2, C17.1, C18.1, C19.1, D12.2, J17.1, J26.2, J26.74, MEAS1.2, MEAS1.4, R28.2, R29.2
3.3V2: 3V3_LED2.2, C28.1, C29.1, C30.1, D19.2, J31.1, J40.2, J40.74, MEAS2.2, MEAS2.4, R43.2, R44.2
3.3V3: 3V3_LED3.2, C39.1, C40.1, C41.1, D26.2, J45.1, J54.2, J54.74, MEAS3.2, MEAS3.4, R58.2, R59.2
3.3V4: 3V3_LED4.2, C51.1, C52.1, C53.1, D33.2, J59.1, J68.2, J68.74, MEAS4.2, MEAS4.4, R73.2, R74.2
3.3V5: 3V3_LED5.2, C62.1, C63.1, C64.1, D40.2, J73.1, J82.2, J82.74, MEAS5.2, MEAS5.4, R88.2, R89.2
3.3V6: 3V3_LED6.2, C73.1, C74.1, C75.1, D47.2, J87.1, J96.2, J96.74, MEAS6.2, MEAS6.4, R103.2, R104.2
3.3V7: 3V3_LED7.2, C84.1, C85.1, C86.1, D54.2, J101.1, J110.2, J110.74, MEAS7.2, MEAS7.4, R118.2, R119.2
3.3V_EN: J6.4, VE.1
3.3V_EN1: J26.4, VE1.1
3.3V_EN2: J40.4, VE2.1
3.3V_EN3: J54.4, VE3.1
3.3V_EN4: J68.4, VE4.1
3.3V_EN5: J82.4, VE5.1
3.3V_EN6: J96.4, VE6.1
3.3V_EN7: J110.4, VE7.1
3.3V_EN_VE: D1.C, R5.1, U5.5, VE.2
3.3V_EN_VE1: D9.C, R23.1, U4.5, VE1.2
3.3V_EN_VE2: D16.C, R38.1, U9.5, VE2.2
3.3V_EN_VE3: D23.C, R53.1, U13.5, VE3.2
3.3V_EN_VE4: D30.C, R68.1, U17.5, VE4.2
3.3V_EN_VE5: D37.C, R83.1, U21.5, VE5.2
3.3V_EN_VE6: D44.C, R98.1, U25.5, VE6.2
3.3V_EN_VE7: D51.C, R113.1, U29.5, VE7.2
3.3V_LP: C8.1, C46.1, J5.4, J10.1, J10.2, J10.3, J11.VCC, J12.1, R15.2, U3.5
3.3V_LP1: C11.1, C21.1, J19.1, J19.2, J19.3, J20.VCC, J24.1, J25.4, R30.2, U8.5
3.3V_LP2: C23.1, C32.1, J33.1, J33.2, J33.3, J34.VCC, J38.1, J39.4, R45.2, U12.5
3.3V_LP3: C34.1, C43.1, J47.1, J47.2, J47.3, J48.VCC, J52.1, J53.4, R60.2, U16.5
3.3V_LP4: C45.1, C55.1, J61.1, J61.2, J61.3, J62.VCC, J66.1, J67.4, R75.2, U20.5
3.3V_LP5: C57.1, C66.1, J75.1, J75.2, J75.3, J76.VCC, J80.1, J81.4, R90.2, U24.5
3.3V_LP6: C68.1, C77.1, J89.1, J89.2, J89.3, J90.VCC, J94.1, J95.4, R105.2, U28.5
3.3V_LP7: C79.1, C88.1, J103.1, J103.2, J103.3, J104.VCC, J108.1, J109.4, R120.2, U32.5
5V: C3.1, D2.A, D3.C, MEAS_BATT.1, MEAS_BATT.3, U2.4
5V1: C16.1, D10.A, D11.C, MEAS_BATT1.1, MEAS_BATT1.3, U6.4
5V2: C27.1, D17.A, D18.C, MEAS_BATT2.1, MEAS_BATT2.3, U10.4
5V3: C38.1, D24.A, D25.C, MEAS_BATT3.1, MEAS_BATT3.3, U14.4
5V4: C50.1, D31.A, D32.C, MEAS_BATT4.1, MEAS_BATT4.3, U18.4
5V5: C61.1, D38.A, D39.C, MEAS_BATT5.1, MEAS_BATT5.3, U22.4
5V6: C72.1, D45.A, D46.C, MEAS_BATT6.1, MEAS_BATT6.3, U26.4
5V7: C83.1, D52.A, D53.C, MEAS_BATT7.1, MEAS_BATT7.3, U30.4
!BOOT!: J6.11, S2.3, S2.4
!BOOT!1: J26.11, S4.3, S4.4
!BOOT!2: J40.11, S6.3, S6.4
!BOOT!3: J54.11, S8.3, S8.4
!BOOT!4: J68.11, S10.3, S10.4
!BOOT!5: J82.11, S12.3, S12.4
!BOOT!6: J96.11, S14.3, S14.4
!BOOT!7: J110.11, S16.3, S16.4
!RESET!: J2.10, J6.6, J13.1, S1.3, S1.4
!RESET!1: J17.10, J26.6, J28.1, S3.3, S3.4
!RESET!2: J31.10, J40.6, J42.1, S5.3, S5.4
!RESET!3: J45.10, J54.6, J56.1, S7.3, S7.4
!RESET!4: J59.10, J68.6, J70.1, S9.3, S9.4
!RESET!5: J73.10, J82.6, J84.1, S11.3, S11.4
!RESET!6: J87.10, J96.6, J98.1, S13.3, S13.4
!RESET!7: J101.10, J110.6, J112.1, S15.3, S15.4
A0: J6.34, J8.1
A1: J6.38, J8.2
A2: J18.1, J26.34
A3: J18.2, J26.38
A4: J32.1, J40.34
A5: J32.2, J40.38
A6: J46.1, J54.34
A7: J46.2, J54.38
A8: J60.1, J68.34
A9: J60.2, J68.38
A10: J74.1, J82.34
A11: J74.2, J82.38
A12: J88.1, J96.34
A13: J88.2, J96.38
A14: J102.1, J110.34
A15: J102.2, J110.38
CHG_LED: R7.1, U2.1
CHG_LED1: R25.1, U6.1
CHG_LED2: R40.1, U10.1
CHG_LED3: R55.1, U14.1
CHG_LED4: R70.1, U18.1
CHG_LED5: R85.1, U22.1
CHG_LED6: R100.1, U26.1
CHG_LED7: R115.1, U30.1
D0: J6.10, J8.5
D1: J6.18, J8.6
D2: J18.5, J26.10
D3: J18.6, J26.18
D4: J32.5, J40.10
D5: J32.6, J40.18
D6: J46.5, J54.10
D7: J46.6, J54.18
D8: J60.5, J68.10
D9: J60.6, J68.18
D10: J74.5, J82.10
D11: J74.6, J82.18
D12: J88.5, J96.10
D13: J88.6, J96.18
D14: J102.5, J110.10
D15: J102.6, J110.18
GND: BT1.-, C1.2, C2.-, C3.2, C4.2, C5.2, C6.2, C7.2, C8.2, C9.2, C13.2, C46.2, D1.A, D5.C, D7.C, H5.1, J1.GND, J1.GND2, J2.3, J2.5, J2.9, J3.1, J4.1, J5.1, J6.1, J6.7, J6.33, J6.36, J6.39, J6.45, J6.75, J7.2, J10.4, J10.5, J10.6, J11.CD1, J11.GND, J11.GND1, J11.GND3, J12.6, J14.1, R2.1, R3.1, R6.1, R9.1, S1.1, S1.2, S2.1, S2.2, U1.2, U2.2, U3.2, U5.4, U5.EP
GND1: BT2.-, C10.2, C11.2, C12.2, C14.-, C15.2, C16.2, C17.2, C18.2, C19.2, C20.2, C21.2, D9.A, D13.C, D14.C, H11.1, J15.GND, J15.GND2, J16.1, J17.3, J17.5, J17.9, J19.4, J19.5, J19.6, J20.CD1, J20.GND, J20.GND1, J20.GND3, J21.1, J22.1, J23.2, J24.6, J25.1, J26.1, J26.7, J26.33, J26.36, J26.39, J26.45, J26.75, R16.1, R17.1, R21.1, R24.1, S3.1, S3.2, S4.1, S4.2, U4.4, U4.EP, U6.2, U7.2, U8.2
GND2: BT3.-, C22.2, C23.2, C24.2, C25.-, C26.2, C27.2, C28.2, C29.2, C30.2, C31.2, C32.2, D16.A, D20.C, D21.C, H17.1, J29.GND, J29.GND2, J30.1, J31.3, J31.5, J31.9, J33.4, J33.5, J33.6, J34.CD1, J34.GND, J34.GND1, J34.GND3, J35.1, J36.1, J37.2, J38.6, J39.1, J40.1, J40.7, J40.33, J40.36, J40.39, J40.45, J40.75, R31.1, R32.1, R36.1, R39.1, S5.1, S5.2, S6.1, S6.2, U9.4, U9.EP, U10.2, U11.2, U12.2
GND3: BT4.-, C33.2, C34.2, C35.2, C36.-, C37.2, C38.2, C39.2, C40.2, C41.2, C42.2, C43.2, D23.A, D27.C, D28.C, H23.1, J43.GND, J43.GND2, J44.1, J45.3, J45.5, J45.9, J47.4, J47.5, J47.6, J48.CD1, J48.GND, J48.GND1, J48.GND3, J49.1, J50.1, J51.2, J52.6, J53.1, J54.1, J54.7, J54.33, J54.36, J54.39, J54.45, J54.75, R46.1, R47.1, R51.1, R54.1, S7.1, S7.2, S8.1, S8.2, U13.4, U13.EP, U14.2, U15.2, U16.2
GND4: BT5.-, C44.2, C45.2, C47.2, C48.-, C49.2, C50.2, C51.2, C52.2, C53.2, C54.2, C55.2, D30.A, D34.C, D35.C, H29.1, J57.GND, J57.GND2, J58.1, J59.3, J59.5, J59.9, J61.4, J61.5, J61.6, J62.CD1, J62.GND, J62.GND1, J62.GND3, J63.1, J64.1, J65.2, J66.6, J67.1, J68.1, J68.7, J68.33, J68.36, J68.39, J68.45, J68.75, R61.1, R62.1, R66.1, R69.1, S9.1, S9.2, S10.1, S10.2, U17.4, U17.EP, U18.2, U19.2, U20.2
GND5: BT6.-, C56.2, C57.2, C58.2, C59.-, C60.2, C61.2, C62.2, C63.2, C64.2, C65.2, C66.2, D37.A, D41.C, D42.C, H35.1, J71.GND, J71.GND2, J72.1, J73.3, J73.5, J73.9, J75.4, J75.5, J75.6, J76.CD1, J76.GND, J76.GND1, J76.GND3, J77.1, J78.1, J79.2, J80.6, J81.1, J82.1, J82.7, J82.33, J82.36, J82.39, J82.45, J82.75, R76.1, R77.1, R81.1, R84.1, S11.1, S11.2, S12.1, S12.2, U21.4, U21.EP, U22.2, U23.2, U24.2
GND6: BT7.-, C67.2, C68.2, C69.2, C70.-, C71.2, C72.2, C73.2, C74.2, C75.2, C76.2, C77.2, D44.A, D48.C, D49.C, H41.1, J85.GND, J85.GND2, J86.1, J87.3, J87.5, J87.9, J89.4, J89.5, J89.6, J90.CD1, J90.GND, J90.GND1, J90.GND3, J91.1, J92.1, J93.2, J94.6, J95.1, J96.1, J96.7, J96.33, J96.36, J96.39, J96.45, J96.75, R91.1, R92.1, R96.1, R99.1, S13.1, S13.2, S14.1, S14.2, U25.4, U25.EP, U26.2, U27.2, U28.2
GND7: BT8.-, C78.2, C79.2, C80.2, C81.-, C82.2, C83.2, C84.2, C85.2, C86.2, C87.2, C88.2, D51.A, D55.C, D56.C, H47.1, J99.GND, J99.GND2, J100.1, J101.3, J101.5, J101.9, J103.4, J103.5, J103.6, J104.CD1, J104.GND, J104.GND1, J104.GND3, J105.1, J106.1, J107.2, J108.6, J109.1, J110.1, J110.7, J110.33, J110.36, J110.39, J110.45, J110.75, R106.1, R107.1, R111.1, R114.1, S15.1, S15.2, S16.1, S16.2, U29.4, U29.EP, U30.2, U31.2, U32.2
HEADER_!CS!: J6.40, J12.5
HEADER_!CS!1: J24.5, J26.40
HEADER_!CS!2: J38.5, J40.40
HEADER_!CS!3: J52.5, J54.40
HEADER_!CS!4: J66.5, J68.40
HEADER_!CS!5: J80.5, J82.40
HEADER_!CS!6: J94.5, J96.40
HEADER_!CS!7: J108.5, J110.40
I2C_!INT!: J6.16, J9.1
I2C_!INT!1: J26.16, J27.1
I2C_!INT!2: J40.16, J41.1
I2C_!INT!3: J54.16, J55.1
I2C_!INT!4: J68.16, J69.1
I2C_!INT!5: J82.16, J83.1
I2C_!INT!6: J96.16, J97.1
I2C_!INT!7: J110.16, J111.1
I2C_SCL: J3.4, J6.14, J14.4, R4.1
I2C_SCL1: J16.4, J21.4, J26.14, R20.1
I2C_SCL2: J30.4, J35.4, J40.14, R35.1
I2C_SCL3: J44.4, J49.4, J54.14, R50.1
I2C_SCL4: J58.4, J63.4, J68.14, R65.1
I2C_SCL5: J72.4, J77.4, J82.14, R80.1
I2C_SCL6: J86.4, J91.4, J96.14, R95.1
I2C_SCL7: J100.4, J105.4, J110.14, R110.1
I2C_SDA: J3.3, J6.12, J14.3, R1.1
I2C_SDA1: J16.3, J21.3, J26.12, R19.1
I2C_SDA2: J30.3, J35.3, J40.12, R34.1
I2C_SDA3: J44.3, J49.3, J54.12, R49.1
I2C_SDA4: J58.3, J63.3, J68.12, R64.1
I2C_SDA5: J72.3, J77.3, J82.12, R79.1
I2C_SDA6: J86.3, J91.3, J96.12, R94.1
I2C_SDA7: J100.3, J105.3, J110.12, R109.1
unnamed: MEAS.1, MEAS.3, U5.1
unnamed: JP1.3, R4.2
unnamed: JP1.1, R1.2
unnamed: D2.C, R7.2
unnamed: D5.A, R11.1
unnamed: 3V3_LED.1, R11.2
unnamed: R6.2, U2.5
unnamed: R12.2, VIN_LED.1
unnamed: D7.A, R12.1
unnamed: J1.A5, R2.2
unnamed: J1.B5, R3.2
unnamed: J15.A5, R16.2
unnamed: J15.B5, R17.2
unnamed: BT1.+, D6.A, R8.1
unnamed: BT2.+, D8.A, R18.1
unnamed: JP2.3, R20.2
unnamed: JP2.1, R19.2
unnamed: MEAS1.1, MEAS1.3, U4.1
unnamed: R24.2, U6.5
unnamed: D10.C, R25.2
unnamed: 3V3_LED1.1, R26.2
unnamed: D13.A, R26.1
unnamed: R27.2, VIN_LED1.1
unnamed: D14.A, R27.1
unnamed: J29.A5, R31.2
unnamed: J29.B5, R32.2
unnamed: BT3.+, D15.A, R33.1
unnamed: JP3.3, R35.2
unnamed: JP3.1, R34.2
unnamed: MEAS2.1, MEAS2.3, U9.1
unnamed: R39.2, U10.5
unnamed: D17.C, R40.2
unnamed: 3V3_LED2.1, R41.2
unnamed: D20.A, R41.1
unnamed: R42.2, VIN_LED2.1
unnamed: D21.A, R42.1
unnamed: J43.A5, R46.2
unnamed: J43.B5, R47.2
unnamed: BT4.+, D22.A, R48.1
unnamed: JP4.3, R50.2
unnamed: JP4.1, R49.2
unnamed: MEAS3.1, MEAS3.3, U13.1
unnamed: R54.2, U14.5
unnamed: D24.C, R55.2
unnamed: 3V3_LED3.1, R56.2
unnamed: D27.A, R56.1
unnamed: R57.2, VIN_LED3.1
unnamed: D28.A, R57.1
unnamed: J57.A5, R61.2
unnamed: J57.B5, R62.2
unnamed: BT5.+, D29.A, R63.1
unnamed: JP5.3, R65.2
unnamed: JP5.1, R64.2
unnamed: MEAS4.1, MEAS4.3, U17.1
unnamed: R69.2, U18.5
unnamed: D31.C, R70.2
unnamed: 3V3_LED4.1, R71.2
unnamed: D34.A, R71.1
unnamed: R72.2, VIN_LED4.1
unnamed: D35.A, R72.1
unnamed: J71.A5, R76.2
unnamed: J71.B5, R77.2
unnamed: BT6.+, D36.A, R78.1
unnamed: JP6.3, R80.2
unnamed: JP6.1, R79.2
unnamed: MEAS5.1, MEAS5.3, U21.1
unnamed: R84.2, U22.5
unnamed: D38.C, R85.2
unnamed: 3V3_LED5.1, R86.2
unnamed: D41.A, R86.1
unnamed: R87.2, VIN_LED5.1
unnamed: D42.A, R87.1
unnamed: J85.A5, R91.2
unnamed: J85.B5, R92.2
unnamed: BT7.+, D43.A, R93.1
unnamed: JP7.3, R95.2
unnamed: JP7.1, R94.2
unnamed: MEAS6.1, MEAS6.3, U25.1
unnamed: R99.2, U26.5
unnamed: D45.C, R100.2
unnamed: 3V3_LED6.1, R101.2
unnamed: D48.A, R101.1
unnamed: R102.2, VIN_LED6.1
unnamed: D49.A, R102.1
unnamed: J99.A5, R106.2
unnamed: J99.B5, R107.2
unnamed: BT8.+, D50.A, R108.1
unnamed: JP8.3, R110.2
unnamed: JP8.1, R109.2
unnamed: MEAS7.1, MEAS7.3, U29.1
unnamed: R114.2, U30.5
unnamed: D52.C, R115.2
unnamed: 3V3_LED7.1, R116.2
unnamed: D55.A, R116.1
unnamed: R117.2, VIN_LED7.1
unnamed: D56.A, R117.1
PERIPHERAL_PWR_CTRL: J6.42, R14.1, U3.3
PERIPHERAL_PWR_CTRL1: J26.42, R29.1, U8.3
PERIPHERAL_PWR_CTRL2: J40.42, R44.1, U12.3
PERIPHERAL_PWR_CTRL3: J54.42, R59.1, U16.3
PERIPHERAL_PWR_CTRL4: J68.42, R74.1, U20.3
PERIPHERAL_PWR_CTRL5: J82.42, R89.1, U24.3
PERIPHERAL_PWR_CTRL6: J96.42, R104.1, U28.3
PERIPHERAL_PWR_CTRL7: J110.42, R119.1, U32.3
PWM0: J6.32, J8.3
PWM1: J6.47, J8.4
PWM2: J18.3, J26.32
PWM3: J18.4, J26.47
PWM4: J32.3, J40.32
PWM5: J32.4, J40.47
PWM6: J46.3, J54.32
PWM7: J46.4, J54.47
PWM8: J60.3, J68.32
PWM9: J60.4, J68.47
PWM10: J74.3, J82.32
PWM11: J74.4, J82.47
PWM12: J88.3, J96.32
PWM13: J88.4, J96.47
PWM14: J102.3, J110.32
PWM15: J102.4, J110.47
QWIIC_PWR: C9.1, J3.2, J14.2, JP1.2, U1.5
QWIIC_PWR1: C20.1, J16.2, J21.2, JP2.2, U7.5
QWIIC_PWR2: C31.1, J30.2, J35.2, JP3.2, U11.5
QWIIC_PWR3: C42.1, J44.2, J49.2, JP4.2, U15.5
QWIIC_PWR4: C54.1, J58.2, J63.2, JP5.2, U19.5
QWIIC_PWR5: C65.1, J72.2, J77.2, JP6.2, U23.5
QWIIC_PWR6: C76.1, J86.2, J91.2, JP7.2, U27.5
QWIIC_PWR7: C87.1, J100.2, J105.2, JP8.2, U31.5
QWIIC_PWR_CTRL: J6.44, R13.1, U1.3
QWIIC_PWR_CTRL1: J26.44, R28.1, U7.3
QWIIC_PWR_CTRL2: J40.44, R43.1, U11.3
QWIIC_PWR_CTRL3: J54.44, R58.1, U15.3
QWIIC_PWR_CTRL4: J68.44, R73.1, U19.3
QWIIC_PWR_CTRL5: J82.44, R88.1, U23.3
QWIIC_PWR_CTRL6: J96.44, R103.1, U27.3
QWIIC_PWR_CTRL7: J110.44, R118.1, U31.3
RTC_3V: D4.3, D6.C, J6.72, R8.2
RTC_3V1: D8.C, D12.3, J26.72, R18.2
RTC_3V2: D15.C, D19.3, J40.72, R33.2
RTC_3V3: D22.C, D26.3, J54.72, R48.2
RTC_3V4: D29.C, D33.3, J68.72, R63.2
RTC_3V5: D36.C, D40.3, J82.72, R78.2
RTC_3V6: D43.C, D47.3, J96.72, R93.2
RTC_3V7: D50.C, D54.3, J110.72, R108.2
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

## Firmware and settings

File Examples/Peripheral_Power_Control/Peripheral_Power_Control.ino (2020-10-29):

/*

*/

int headerCS = G0;
int peripheralPowerControl = G1;
int qwiicPowerControl = G2;

#if defined(ARDUINO_ARCH_APOLLO3)

#elif defined(__IMXRT1062__)

#endif

void setup() {
  pinMode(LED_BUILTIN, OUTPUT);
  pinMode(headerCS, OUTPUT);
  pinMode(peripheralPowerControl, OUTPUT);
  pinMode(qwiicPowerControl, OUTPUT);

}

void loop() {
  digitalWrite(LED_BUILTIN, HIGH);
  digitalWrite(headerCS, HIGH);
  peripheralPowerOn();
  qwiicPowerOn();
  delay(2000); 
  digitalWrite(LED_BUILTIN, LOW);
  digitalWrite(headerCS, LOW);
  peripheralPowerOff();
  qwiicPowerOff();
  delay(2000);
}

//Qwiic connector power is controlled from an LDO voltage regulator
void qwiicPowerOn()
{
  digitalWrite(qwiicPowerControl, HIGH);
}
void qwiicPowerOff()
{
  digitalWrite(qwiicPowerControl, LOW);
}

//3V3 peripheral power is controlled from an LDO voltage regulator
void peripheralPowerOn()
{
  digitalWrite(peripheralPowerControl, HIGH);
}
void peripheralPowerOff()
{
  digitalWrite(peripheralPowerControl, LOW);
}

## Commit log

2020-05-05 File cleanup
    [MicroMod-Datalogging-CarrierBoard.brd, MicroMod-Datalogging-CarrierBoard.sch]
2020-05-05 Update v-reg device
    [MicroMod-Datalogging-CarrierBoard.brd, MicroMod-Datalogging-CarrierBoard.sch]
2020-08-14 Change peripheral power to regulators. Upgrade buzzard labels. Add VE jumper.
    [MicroMod-Datalogging-CarrierBoard-Panel.GBL, MicroMod-Datalogging-CarrierBoard-Panel.GBO, MicroMod-Datalogging-CarrierBoard-Panel.GBP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]
2020-09-10 Update MicroMod connector with new SPI port assignments.
    [MicroMod-Datalogging-CarrierBoard.brd, MicroMod-Datalogging-CarrierBoard.sch]
2020-10-29 Swap logic of power control functions
    [Peripheral_Power_Control.ino, Power_Control.ino]
2021-11-05 Change SD to pure SPI connection.
    [MicroMod-Datalogging-CarrierBoard-Panel.brd, MicroMod-Datalogging-CarrierBoard.brd, MicroMod-Datalogging-CarrierBoard.sch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]

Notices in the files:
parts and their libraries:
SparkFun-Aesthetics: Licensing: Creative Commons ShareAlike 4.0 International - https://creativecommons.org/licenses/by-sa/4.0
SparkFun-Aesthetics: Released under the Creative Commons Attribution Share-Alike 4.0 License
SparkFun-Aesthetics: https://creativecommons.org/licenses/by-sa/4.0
